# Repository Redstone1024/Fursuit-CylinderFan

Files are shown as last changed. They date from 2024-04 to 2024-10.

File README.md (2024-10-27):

# Redcraft Fursuit Cylinder Fan

A Simple Rechargeable Cylinder Fan for Fursuit

Shield: [][cc-by]

This work is licensed under a
[Creative Commons Attribution 4.0 International License][cc-by].

[][cc-by]

[cc-by]: http://creativecommons.org/licenses/by/4.0/
[cc-by-image]: https://i.creativecommons.org/l/by/4.0/88x31.png
[cc-by-shield]: https://img.shields.io/badge/License-CC%20BY%204.0-lightgrey.svg

## Installation

> **Note**: The BOM.csv is based on the Type-C with finished battery variant, if you choose another variant please read below first.

### PCB

First, solder the components to the PCB, you can refer to the method provided in the [Link](https://www.myredstone.top/archives/5215).

The non-silkscreened 0Ohm resistor next to U3 is used to configure the fan PWM positive and negative.
For DV05028B12U, use the 0Ohm resistor to connect pad closest to **inside** PCB (positive PWM).

The JP2 connector is used to connect the battery level indicator module, so **don't** solder PZ2.54-2X2P.

If you choose the DC version, you only need to solder C21 C22 JP1 JP3 JP4 R23 R24 R25 R26 U2 U3 VR1.

If you choose the Type-C version, You can refer to the following procedure to verify that the PCB is working, and refer FAQ if there is an abnormality.

> **Note**: No abnormally high temperatures in the IC and other components throughout the process.

> **Note**: The following tests are performed with a **good** battery.

> **Note**: If your Type-C PD power supply is unable to detect the current status, you can apply an adjustable power supply directly on the Type-C or C23 (**left** end is positive). But don't forget to test if it still works when connected to a standard Type-C PD power supply.

1. Ensure that there is **no shorts** for C1 C2 C23 and that their resistance is at the MOhm level (C23 is at the kOhm level).
2. Ensure that there are **no false shorts** between the IP2368 and Type-C pins and to GND.
3. Ensure LEDs are oriented and colored correctly.
4. When connected to a standard Type-C PD power supply and **without** battery.
	1. Ensure the red light are **on** and the blue light is **off**.
	2. Ensure the green light are on if the power supply supports 20V.
    3. Ensure the power supply should be around **20V** (or 5V, 9V, 12V, 15V depending on the power supply).
	4. Ensure the power supply should be around **0.6W**.
	5. Ensure the C2 voltage should be around **12.6V**.
5. Insert a battery of less than **50%** capacity, ensure the red light blinks **4** times and then goes out.
6. When connected to a standard Type-C PD power supply with a **50%** capacity battery (**Pay attention to high temperature**).
	1. Ensure the red light **comes on quickly without blinking** and the blue light is **off**.
	2. Ensure the green light are on if the power supply supports 20V.
	3. Within IC protocol negotiation, ensure the power supply should be around **0.6W**.
	4. After IC protocol negotiation, ensure the power supply should be about **24W** (or 12W for 5V, 9V, 12V, 15V).
	5. After IC protocol negotiation, ensure the voltage across R9 should be **10mV** (**right** end is positive).
7. After unplugging the standard Type-C PD power supply, ensure the red and green lights goes off in about 1 second.
8. When the battery is fully charged, ensure the red light will be off and the blue light wull be on.
9. When connected to a fast charging protocol tester.
	1. Ensure the red light **comes on quickly without blinking** and the blue light is **off**.
	2. Ensure the green light are on if you are testing outputs above 15V.
	3. Ensure support PD3.0 30W, APPEL 2.4A, BC1.2DCP, QC3.0 5V-12V, AFC 25W, FCP 24W, SCP 25W, etc.
10. Connect the fan and make sure the fan can rotate and adjust the speed properly.
11. Ensure the battery level meter can correctly display the battery level.

### 3D Printed Parts

> **Note**: The following parts are printed with a 0.4mm nozzle and 0.2mm layer height.

> **Note**: STLs not mentioned here can be printed using the auto-orientation directly

**CylinderFan-Master-Body.stl** - Position the fan upward and add support to the lower **plane** at the lanyard.

**CylinderFan-Master-FanMount.stl** - Add a cylinder to the large center hole, set up layer 0 top, bottom, and walls with 15% honeycomb fill.

**CylinderFan-Nozzle-\*.stl** - Add support to the outer circle below. Pause the print and add the magnet while the magnet hole closes the layer.

**CylinderFan-Electronic-Body-\*.stl** - Select one of the DC and Type-C versions to print.

**CylinderFan-Electronic-Body-Type-C.stl** - Print the LED translucent faces with a white filament. Add support to bottom slide.

**CylinderFan-Electronic-KnobRing.stl** - Print with TPU and controlle damping through fuzzy skin.

**CylinderFan-Battery-\*.stl** - If you select a finished battery, you only need to print the CylinderFan-Battery-Adapter\*.stl part,  otherwise print other STLs.

### Assembly

A total of three to five AWG24 wires are required:

- **Red** - Connect pin 1 of the toggle switch to pin 4 of PCB JP2.
- **Yellow** - Connect pin 2 of the toggle switch to pin 3 of PCB JP2 and the positive of the Li-ion battery level indicator module.
- **Black** - Connect pin 3 of the toggle switch to pin 2 of PCB JP2 and the negative of the Li-ion battery level indicator module.

Be careful to route these wires through CylinderFan-Electronic-KnobTop.stl and CylinderFan-Electronic-Potentiometer.stl and not to impede the rotation of the structure.

The other parts are simply assembled according to the CAD drawings.

Be careful **NOT** to allow parts to run over, wrap around, or rub the wires.

### FAQ

**Q**: Why is the red light always on and not off or higher than a second when I remove the power while charging?

**A**: Major MOSFET G-pin is disconnected. Resolder the main MOSFETs and make sure there is enough tin in the G-pin.

**Q**: Why is there a large number of unsupported protocols during protocol detection?

**A**: Type-C signal pin is disconnected or IP2368 is disconnected. Resolder them reference [Link](https://www.myredstone.top/archives/5215).

**Q**: Why does the protocol detection show that QC3.0 12V is not supported?

**A**: Major MOSFET G-pin is disconnected. Resolder the main MOSFETs and make sure there is enough tin in the G-pin.

**Q**: Why does the red light not go out and the blue light not come on after a full charge?

**A**: If the red light does not flash when the battery is inserted, the capacitor was charged when the battery was replaced and did not recognize the new battery correctly. Just disconnect the battery and wait for the capacitor to discharge and reinsert it. If the red light blinks four times when the battery is inserted, it means that the MOSFET G-pin is disconnected, so re-solder them.

**Q**: Why does Type-C not make good contact when plugged in?

**A**: Presence of flux in Type-C causing isolated contacts or the temperature or time spent soldering the Type-C is excessive, clean the Type-C or use a new Type-C connector.

**Q**: Why is the input normal but the output blinks red and blue at the same time and the blue blinks for a shorter time than the red?

**A**: Major circuits such as inductors have false soldering, re-solder them.

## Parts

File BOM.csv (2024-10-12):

Category | Qty | Value | Device | Package | Parts | JLC Number | Cost (RMB) | Total (RMB) | Notes
Hardware | 1 | DV05028B12U | Server Inverter PWM Cooling Fan | 5028 | Master | Taobao | 21 | 21 | https://item.taobao.com/item.htm?id=523104273886&skuId=4971326873374 (Additional information required)
Hardware | 4 | M6x2 N52 | RuFeBe Magnet | Print Pause Insert | Master | Taobao | 0.3 | 1.2
Hardware | 6 | M3x8 SHCS | Socket Head Cap Screw | Screw Insert | Master | Taobao | 0.06 | 0.36
Hardware | 6 | M3x4x5 Heatset Insert | Heatset Insert | Heatset Insert | Master | Taobao | 0.142 | 0.852
Electronics | 1 | 6.8x6.8 | PCB | - | - | JLC | 4 | 4
Electronics | 2 | 100uF | Solid Capacitor | PTH | C1 C2 | C171434 | 1.1542 | 2.3084
Electronics | 6 | 22uF | Chip Capacitor | 1210 | C3 C4 C5 C6 C7 C8 | C5204920 | 1.1356 | 6.8136
Electronics | 3 | 1uF | Chip Capacitor | 0603 | C9 C14 C21 | C59302 | 0.033038 | 0.099114
Electronics | 2 | 1.5nF | Chip Capacitor | 0603 | C10 C11 | C1595 | 0.01328 | 0.02656
Electronics | 2 | 100nF | Chip Capacitor | 0603 | C12 C13 | C30926 | 0.014161 | 0.028322
Electronics | 5 | 2.2uF | Chip Capacitor | 0603 | C15 C16 C19 C20 C22 | C99228 | 0.196958 | 0.98479
Electronics | 1 | 10uF | Chip Capacitor | 1206 | C23 | C13585 | 0.211861 | 0.211861
Electronics | 2 | 30V | TVS Diode | SOD-123FL | D1 D2 | C364281 | 0.16685 | 0.3337
Electronics | 1 | 15V | Zener Diode | LL-34 | D3 | C2982205 | 0.083934 | 0.083934
Electronics | 2 | 5819 | Schottky Diode | SOD-123 | D4 D5 | C64885 | 0.090075 | 0.18015 | Used to improve efficiency, NC can be used instead.
Electronics | 1 | TYPE-C-16P-FH | Type-C Connector | SMD | J1 | C709357 | 0.537857 | 0.537857 | Detailed models refer to drawings.
Electronics | 1 | 2 Pin | XH Pin Header | PTH | JP1 | C5341201 | 0.10188 | 0.10188 | Detailed models refer to drawings.
Electronics | 1 | 4 Pin | 2510 Pin Header | PTH | JP3 | Taobao | 0.08 | 0.08 | https://item.taobao.com/item.htm?id=611332398478&skuId=4300784084698
Electronics | 0 | 2 Pin | DC005-5.5X2.5 | PTH | JP4 | Taobao | 0.07 | 0 | https://item.taobao.com/item.htm?id=619138494923&skuId=4372492253675
Electronics | 1 | 5.6uH | Buck-Boost Inductor | 12XX | L1 | C408522 | 4.49 | 4.49
Electronics | 1 | Green | Chip LED | 0603 | LED1 | C84267 | 0.096338 | 0.096338 | Greater than 65W Indicator (This is almost impossible to happen).
Electronics | 1 | Red | Chip LED | 0603 | LED2 | C84263 | 0.059304 | 0.059304 | Battery charging indicator.
Electronics | 1 | Blue | Chip LED | 0603 | LED3 | C84266 | 0.094908 | 0.094908 | Battery full indicator.
Electronics | 1 | RU3030M2 | Chip MOSFET | DFN-8(3X3) | Q1 | C148386 | 1.26387 | 1.26387
Electronics | 4 | NTMFS5C670NLT1G | Chip MOSFET | DFN-8(5X6) | Q2 Q3 Q4 Q5 | C179626 | 3.226276 | 12.905104
Electronics | 2 | 5mOhm 1% | Chip Resistor | 1206 | R1 R9 | C723507 | 1.049 | 2.098 | Sampling resistor requires the use of high-precision low-temperature drift metal film resistors.
Electronics | 1 | 1kOhm | Chip Resistor | 0603 | R12 | C25585 | 0.005449 | 0.005449 | Select Constant Current mode, see IP2368 manual for details.
Electronics | 0 | NC | Chip Resistor | 0603 | R13 | NC | 0 | 0 | Select Normal Li-Ion Battery Mode, see IP2368 manual for details.
Electronics | 1 | 10kOhm 1% | Chip Resistor | 0603 | R14 | C25804 | 0.005732 | 0.005732 | Select 2A constant current, see IP2368 manual for details.
Electronics | 1 | 10kOhm 1% | Chip Resistor | 0603 | R15 | C25804 | 0.005732 | 0.005732 | Select 4.20V charging voltage, see IP2368 manual for details.
Electronics | 1 | 6.2kOhm 1% | Chip Resistor | 0603 | R16 | C4260 | 0.005976 | 0.005976 | Select 5000mAH battery capacity, see IP2368 manual for details.
Electronics | 1 | 9.1kOhm | Chip Resistor | 0603 | R17 | C23260 | 0.006084 | 0.006084 | Select Triple String Mode, see IP2368 manual for details.
Electronics | 3 | 10kOhm | Chip Resistor | 0603 | R11 R18 R22 | C15401 | 0.005462 | 0.016386
Electronics | 1 | 1kOhm | Chip Resistor | 0603 | R19 | C25585 | 0.005449 | 0.005449
Electronics | 2 | 100Ohm | Chip Resistor | 0603 | R20 R21 | C25201 | 0.005427 | 0.010854
Electronics | 2 | 10Ohm 1% | Chip Resistor | 0603 | R2 R10 | C22859 | 0.005672 | 0.011344
Electronics | 2 | 2Ohm | Chip Resistor | 0603 | R3 R4 | C25225 | 0.00674 | 0.01348 | 0Ohm can be used instead.
Electronics | 4 | 15Ohm | Chip Resistor | 0603 | R5 R6 R7 R8 | C22810 | 0.006043 | 0.024172 | 0Ohm can be used instead.
Electronics | 2 | 0Ohm | Chip Resistor | 0603 | R23 R24 | C15402 | 0.005373 | 0.010746 | Used to adjust the upper/lower bound of the potentiometer to control the minimum/maximum fan speed.
Electronics | 1 | 0Ohm | Chip Resistor | 0603 | R25 R26 | C15402 | 0.005373 | 0.005373 | Used to select between using the normal PWM signal and the complementary PWM signal, Only one of these needs to be installed.
Electronics | 1 | IP2368_BZ/IP2368_COUT | Chip IC | QFN-48(7X7) | U1 | Taobao | 10 | 10 | IP2368_COUT is an upgraded version with added bi-directional charging and discharging capabilities.
Electronics | 1 | AP2204K-5.0TRG1 | Chip LDO | SOT23-5 | U2 | C112031 | 0.9611 | 0.9611
Electronics | 1 | GP9101-F20K-L5H5-SW | Chip IC | SOP-8 | U3 | C20415753 | 2.98 | 2.98 | L5H5 Indicates a direct 0%/100% duty cycle PWM output for the lowest/highest 5%.
Electronics | 1 | RV097NS R1S1 10kOhm | Potentiometer | PTH | VR1 | Taobao | 0.9 | 0.9 | https://item.taobao.com/item.htm?id=734259779794&skuId=5075259536179
Electronics | 0 | 5000mAH | Li-ion Battery | 21700 | Battery | Taobao | 16.9 | 0
Electronics | 0 | 2 Pin | XH Pin | Wiring | JP1 | Taobao | 0.02 | 0 | https://item.taobao.com/item.htm?id=520552509861&skuId=4139959196754
Module | 0 | 3S 12.6V | Li-ion Battery Protection Module | Wiring | JP1 | Taobao | 6.33 | 0 | https://detail.tmall.com/item.htm?id=558346048387&skuId=4196293570698
Module | 1 | 3S 12.6V | Li-ion Battery Level Indicator Module | Wiring | JP2 | Taobao | 6.5 | 6.5 | https://detail.tmall.com/item.htm?id=624895263635&skuId=4590761114594
Module | 1 | 3S 12.6V XH2.54 Female No. 2 Wire Sequence | Lithium Battery Pack | Wiring | JP1 | Taobao | 79 | 79 | https://item.taobao.com/item.htm?id=635344873890&skuId=5056598004926 (Additional information required)
Module | 1 | SS12F15V G6 | Toggle Switch | Wiring | JP2 | Taobao | 0.104 | 0.104 | https://detail.tmall.com/item.htm?id=607540947052&skuId=4261603081607
Wire | 450 | AWG24 | Silicone Soft Wire | - | - | Taobao | 0.00064 | 0.288
Filament | 0.01 | 1KG | TPU | - | - | Taobao | 100 | 1
Filament | 0.32 | 1KG | PLA | - | - | Taobao | 29.9 | 9.568

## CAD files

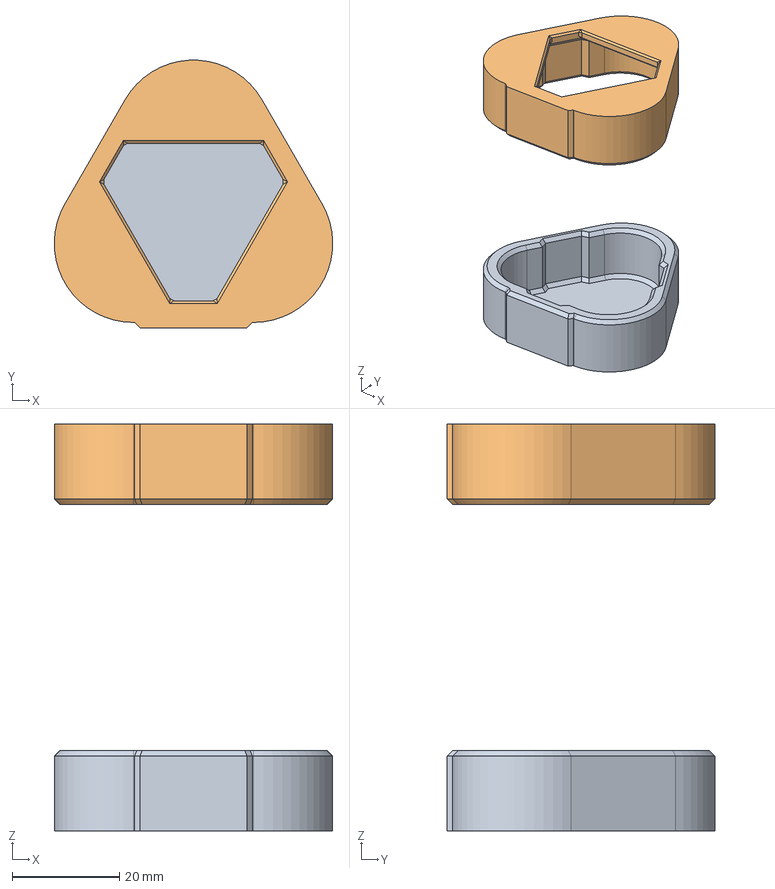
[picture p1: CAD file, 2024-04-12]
CAD/BatteryPackAdapter.step
52.0 x 50.0 x 76.0 mm

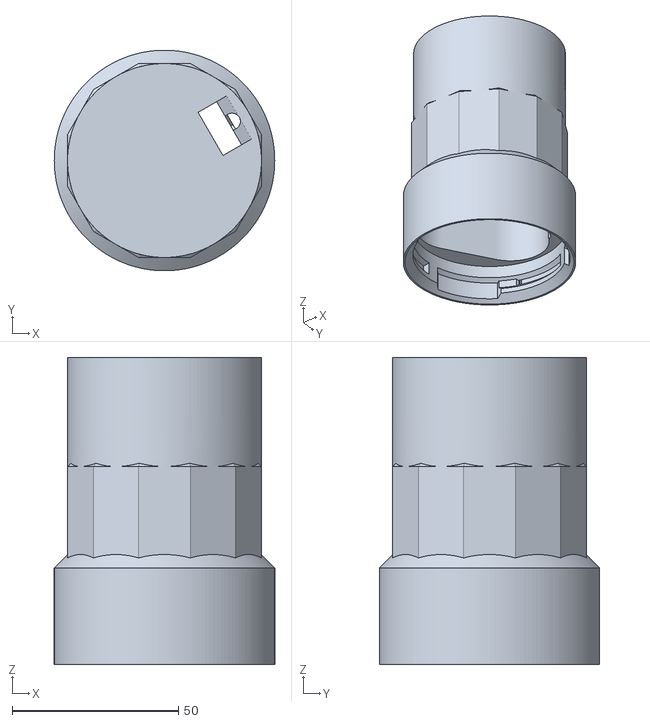
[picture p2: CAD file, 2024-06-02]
STLs/CylinderFan-Master-BatteryMount.stl
66.4 x 66.4 x 92.4

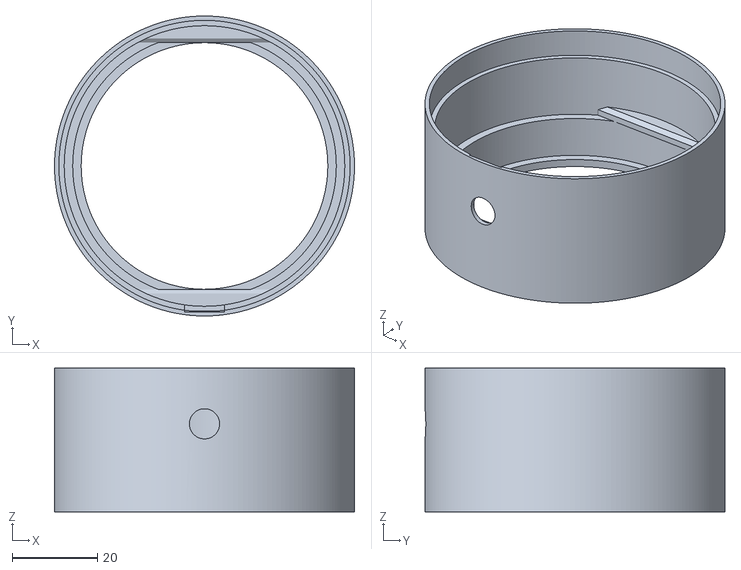
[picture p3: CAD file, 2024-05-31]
STLs/CylinderFan-Electronic-Body-DC.stl
70.6 x 70.6 x 33.8

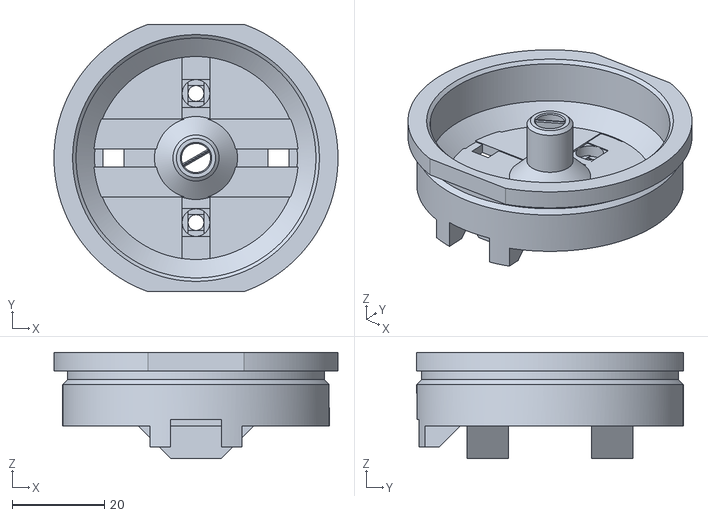
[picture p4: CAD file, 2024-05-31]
STLs/CylinderFan-Electronic-KnobTop.stl
61.6 x 58.0 x 23.0

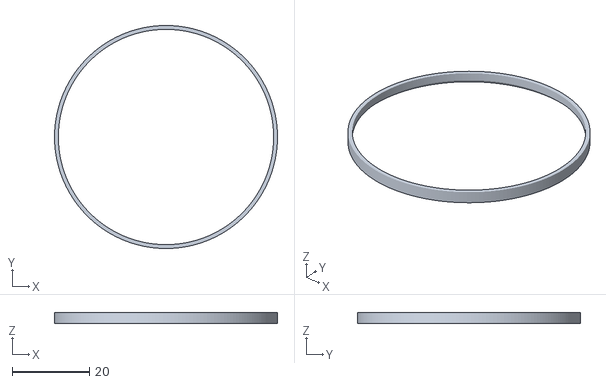
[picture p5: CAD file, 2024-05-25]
STLs/CylinderFan-Electronic-KnobRing.stl
57.8 x 57.8 x 2.90

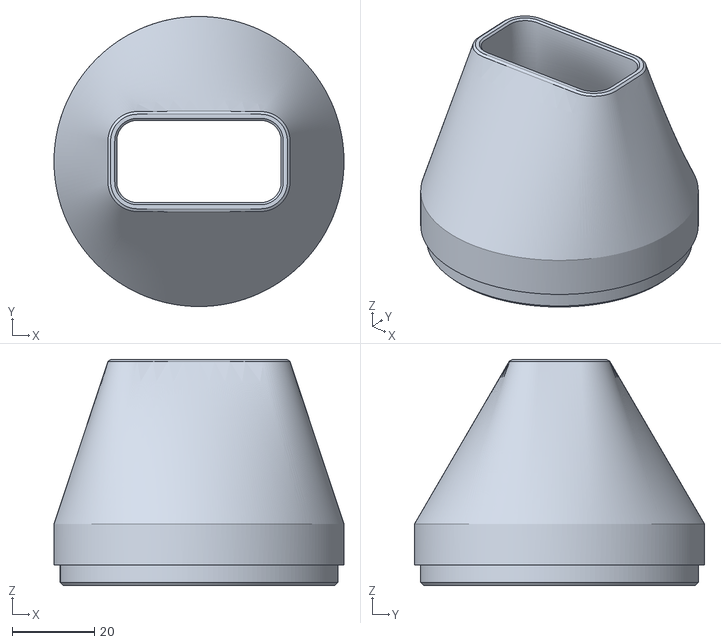
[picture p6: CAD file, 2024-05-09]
STLs/CylinderFan-Nozzle-Flat.stl
70.6 x 70.6 x 55.0

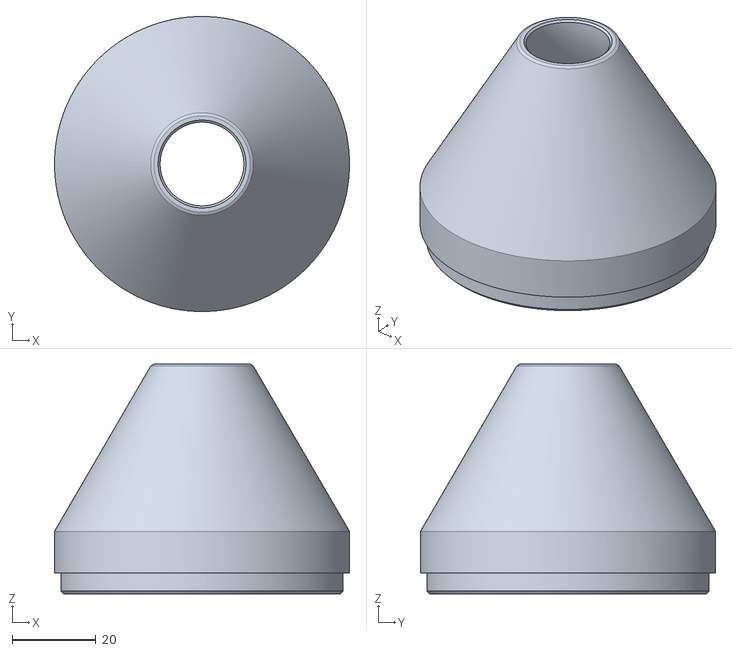
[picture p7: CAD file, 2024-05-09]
STLs/CylinderFan-Nozzle-Round.stl
70.6 x 70.6 x 55.0

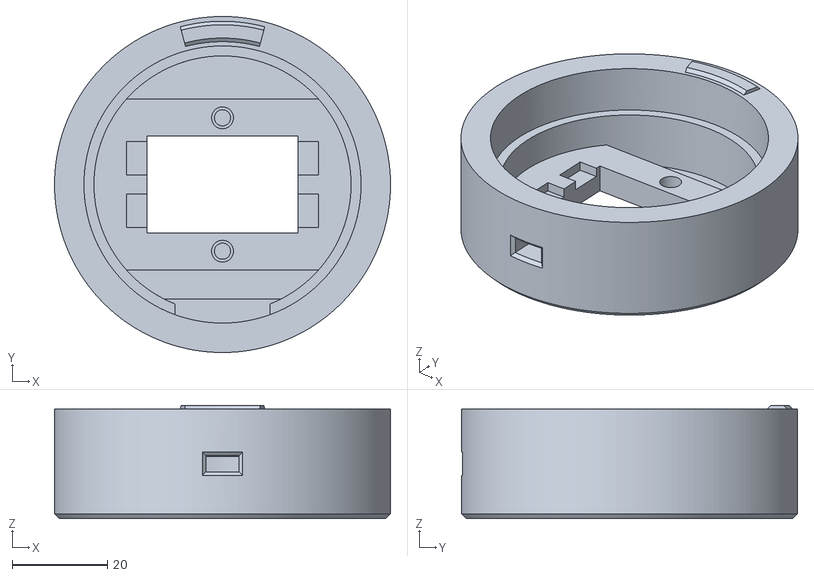
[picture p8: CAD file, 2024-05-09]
STLs/CylinderFan-Electronic-KnobBottom.stl
70.6 x 70.6 x 23.8

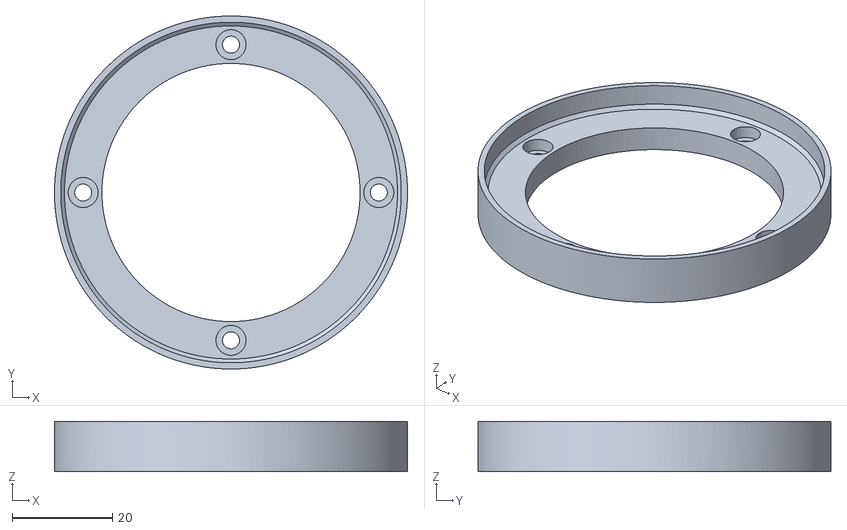
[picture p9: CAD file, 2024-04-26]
STLs/CylinderFan-Master-FanMount.stl
70.6 x 70.6 x 10.0

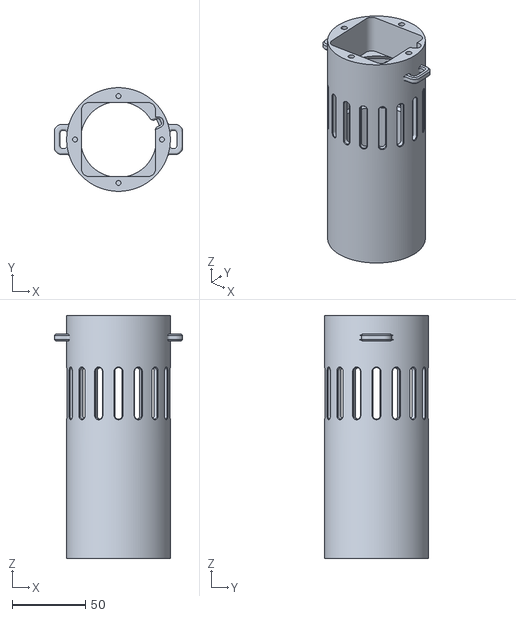
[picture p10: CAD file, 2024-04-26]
STLs/CylinderFan-Master-Body.stl
87.5 x 70.6 x 165.4

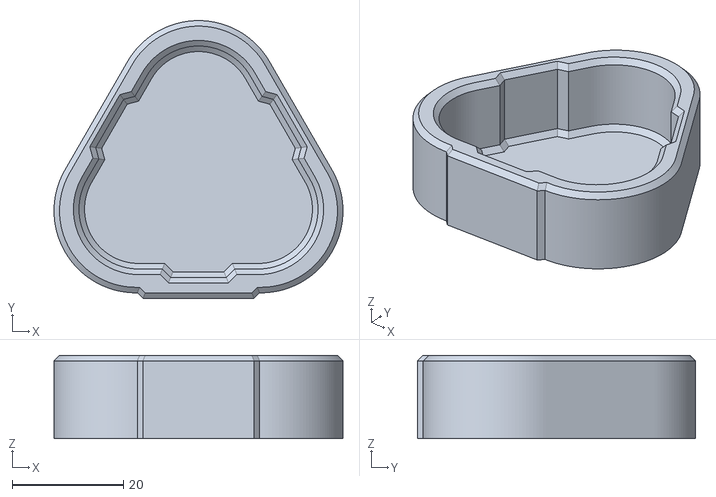
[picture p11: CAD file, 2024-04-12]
STLs/CylinderFan-Battery-AdapterBottom.stl
52.0 x 50.0 x 15.0

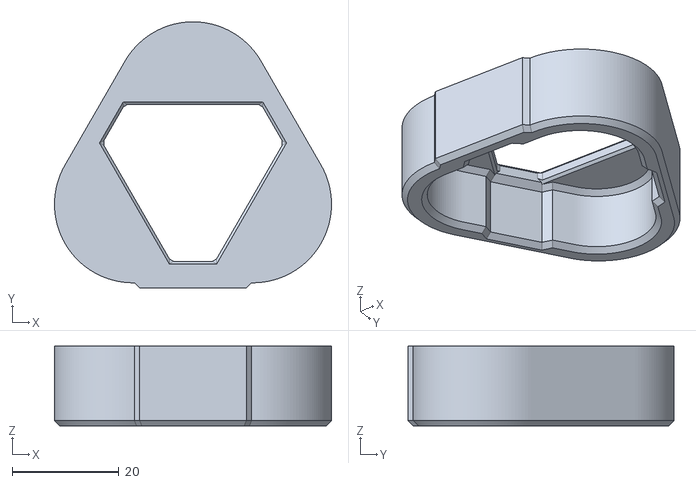
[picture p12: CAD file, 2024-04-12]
STLs/CylinderFan-Battery-AdapterTop.stl
52.0 x 50.0 x 15.0

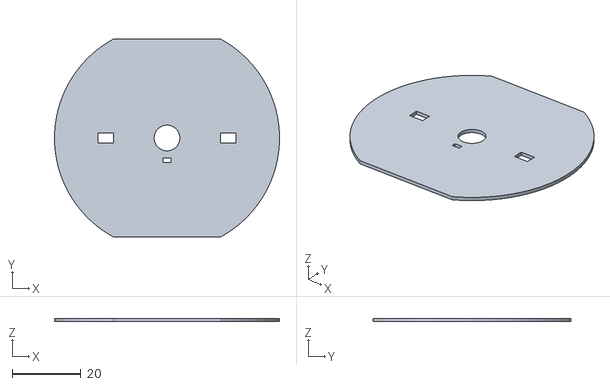
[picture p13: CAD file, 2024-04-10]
STLs/CylinderFan-Electronic-Potentiometer.stl
65.6 x 57.6 x 1.00

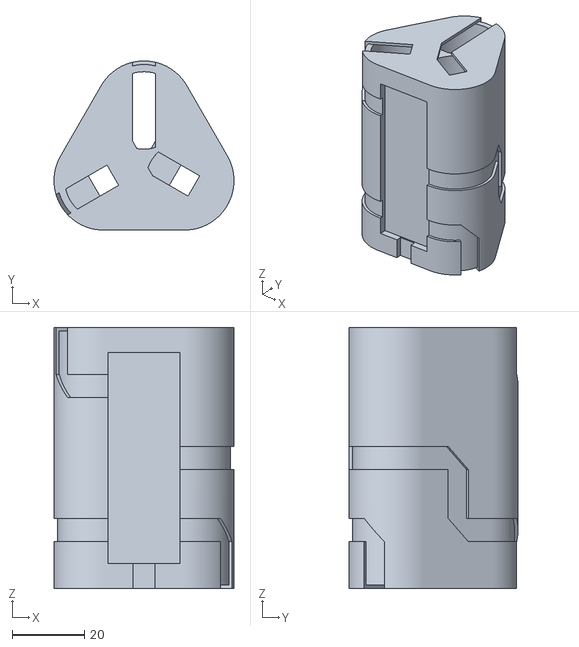
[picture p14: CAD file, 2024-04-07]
STLs/CylinderFan-Battery-Body.stl
50.0 x 47.0 x 72.5

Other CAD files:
STLs/CylinderFan-Electronic-Body-Type-C.stl
STLs/CylinderFan-Battery-Shell.stl
STLs/CylinderFan-Battery-Seal.stl
STLs/CylinderFan-Electronic-Screw.stl
CAD/BatteryPackAdapter.f3d
PCB/CylinderFan-DC-ElectronicsDesign.f3z

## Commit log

2024-04-02 fix(cad): fix the nozzle and PCB fit too tight
    [CylinderFan-Electronic-Body.stl, CylinderFan-Electronic-Screw.stl, CylinderFan-Master-FanMount.stl]
2024-04-04 fix(bom): add potentiometer resistance
    [BOM.csv]
2024-04-04 feat(nozzle): add round and double-ended nozzles
    [CylinderFan-Nozzle-Flat.stl, CylinderFan-Nozzle-Round.stl]
2024-04-07 fix(battery): fix body overhang
    [CylinderFan-Electronic-Battery-Body.stl]
2024-04-07 fix(electronic): change swivel to 30 deg snap fastening prevents wire fraying and tangling
    [CylinderFan-Electronic-Body.stl, CylinderFan-Electronic-Screw.stl, CylinderFan-Master-BatteryMount.stl]
2024-04-08 perf(master): make the battery mounting not rotatable
    [CylinderFan-Master-BatteryMount.stl, CylinderFan-Master-Body.stl]
2024-04-08 refactor(master): replace PFB0512EHF with DV05028B12U in the layout
    [CylinderFan-Master-Body.stl]
2024-04-10 perf(pcb): change ISET to 2A configuration to enhance security
    [BOM.csv]
2024-04-10 perf(*): reduces assembly difficulty of bolted parts and increases stability
    [BOM.csv, CylinderFan-Electronic-Body.stl, CylinderFan-Electronic-KnobBottom.stl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]
2024-04-12 docs(bom): add material prices to the BOM
    [BOM.csv]
2024-04-12 feat(battery): add adaptation to finished battery packs
    [BOM.csv, BatteryPackAdapter.f3d, BatteryPackAdapter.step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]
2024-04-12 style(cad): add color and other material information
2024-04-14 perf(electronic): increase the insertion gap of the potentiometer handle to make assembly easier
    [CylinderFan-Electronic-KnobTop.stl]
2024-04-15 docs(bom): fix 0603 package missing lead 0
    [BOM.csv]
2024-04-21 feat(pcb): add an anti-accidental switch interface on the PCB
2024-04-21 fix(pcb): fix fast charge detection indicator LED
2024-04-25 feat(electronic): add an anti-accidental switch on the knob
    [CylinderFan-Electronic-KnobBottom.stl, CylinderFan-Electronic-KnobTop.stl]
2024-04-26 feat(electronic): add knob rotation limit of 300 deg
    [CylinderFan-Electronic-Body.stl, CylinderFan-Electronic-KnobBottom.stl]
2024-04-26 perf(master): fix lanyard hooks that are hard to hang
    [CylinderFan-Master-Body.stl]
2024-04-26 perf(*): fix screw hole design to prevent damage to the structure by over-tightening
    [CylinderFan-Electronic-KnobTop.stl, CylinderFan-Master-FanMount.stl]
2024-04-26 docs(readme): add printing details for CylinderFan-Master-FanMount.stl
2024-04-27 docs(bom): synchronize BOM list and design files
    [BOM.csv]
2024-05-08 perf(electronic): shrink the Type-C hole makes it more robust
    [CylinderFan-Electronic-Body.stl]
2024-05-09 perf(cad): chamfer sharp parts of the profile
    [CylinderFan-Electronic-KnobBottom.stl, CylinderFan-Nozzle-Flat.stl, CylinderFan-Nozzle-Round.stl]
2024-05-13 perf(pcb): re-layout PCB to optimize signals
2024-05-13 perf(pcb): modify C1 C2 from 220uF to 100uF
2024-05-20 fix(electronic): fix to adapt to new PCB layout
    [CylinderFan-Electronic-Screw.stl]
2024-05-25 feat(electronic): add TPU ring to control damping
    [CylinderFan-Electronic-KnobRing.stl, CylinderFan-Electronic-KnobTop.stl]
2024-05-31 feat(pcb): add PCB layout for DC version
    [CylinderFan-DC-ElectronicsDesign.f3z]
2024-05-31 feat(cad): add DC shell and increase some structural clearances
    [CylinderFan-Electronic-Body-DC.stl, CylinderFan-Electronic-Body-Type-C.stl, CylinderFan-Electronic-Body.stl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]
2024-05-31 docs(*): add some description of the DC variant
    [BOM.csv]
2024-06-02 perf(master): increase master body and battery mount structural clearances
    [CylinderFan-Master-BatteryMount.stl]
2024-08-17 docs(bom): fix broken material link
    [BOM.csv]
2024-09-04 docs(bom): reify heatset insert nut parameters
    [BOM.csv]
2024-10-09 docs(pcb): add interactive html bill of materials
2024-10-12 docs(bom): fix JLC Number for R14
    [BOM.csv]
2024-10-27 docs(readme): clarify the color of the lights during PCB verification

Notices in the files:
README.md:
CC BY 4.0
